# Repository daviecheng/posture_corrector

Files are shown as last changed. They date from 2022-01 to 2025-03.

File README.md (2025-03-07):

# Wearable Posture Corrector Device

## Summary
> A wearable device that alerts the user after prolonged slouching.

Video demonstration is in my GitHub page [here](https://daviecheng.github.io/posture.html)

## Context
- This project utilizes a Scalable, Efficient, and Fast classifieR (SEFR) machine learning algorithm.
  - Fast in both training and prediction while maintaining resource efficiency.
  - Low-power consumption with minimal memory footprint, making it ideal for microcontroller applications.
  - This project uses the `micromlgen` library from this [post](https://eloquentarduino.github.io/2020/07/sefr-a-fast-linear-time-classifier-for-ultra-low-power-devices/).
- The classifier uses 600 training data samples (300 samples each for slouching and non-slouching)
- Input features to the SEFR classifier 
  - Mean acceleration along the X, Y, Z axes
  - Mean RMS acceleration along the X, Y, Z axes
- Device components
  - ATmega328 MCU
  - Lithium Battery Charging Board
  - Pushbutton Power Switch 
  - 3D printed case enclosure
  - Piezo used as an alarm

## Setup
1. Extract training data for both slouching and non-slouching.
2. Copy the training data to a .csv file and label the features as 1 for slouching and 0 for non-slouching.
3. Run the `sefr_ml.py` Python script in `/scripts` with the training data .csv file to generate the C code for the SEFR classifier using the `micromlgen` library.
4. Copy the output and save as a C header file to be included in the project.
5. Use the header file and call the `predict()` function to make predictions using the trained classifier.

## Schematic
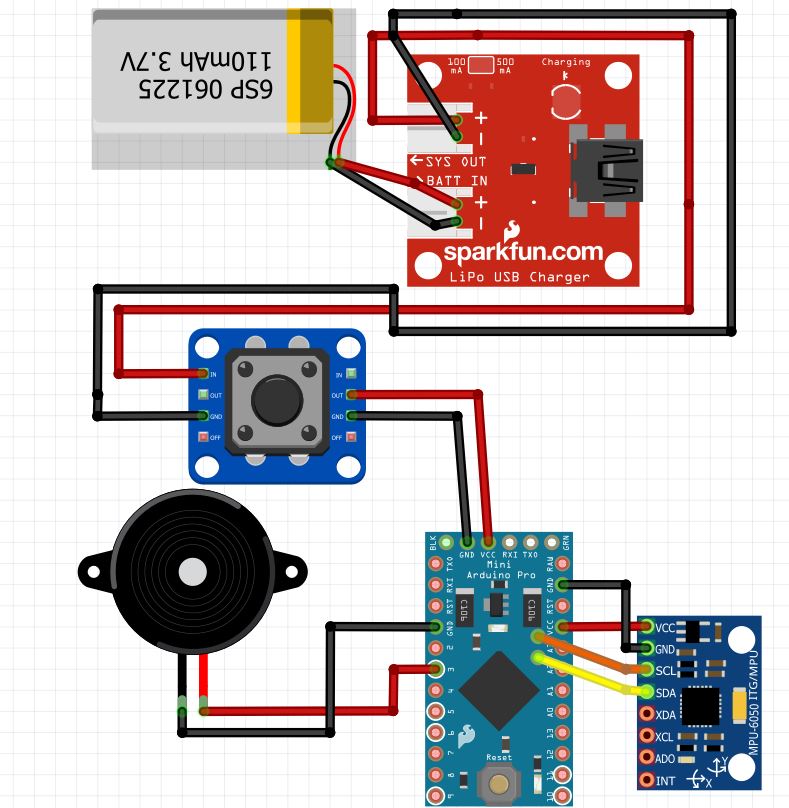
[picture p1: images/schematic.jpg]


## Sequence Diagram
> The device is set to alert the user after approximately 7 seconds of continuous slouching. This setting can be adjusted in the code according to the user's preferences.
```mermaid
sequenceDiagram
    actor User
    participant Power as PowerModule
    participant Manager as PostureManager
    participant SEFR as Classifier
    participant Buzzer as Alarm

    User->>Power : User turns on the device
    Power->>Manager : Setup MPU sensor
    loop Every 2.4 seconds
        User->>Manager : Collects 10 Motion Samples
        Manager->>Manager : Feature extraction
        Manager->>SEFR: Predict
        SEFR->>Manager: Result
        alt Slouching
            Manager->>Manager: Increment Conesecutive Slouches
            alt Consecutive slouches >= 3
                Manager->>Buzzer: Sound Alarm
            end
        else Else
            Manager->>Manager : Reset consecutive slouches
        end

        # Power off flow
        alt Shutdown event
            User->>Power : User turns off the device
        end

    end
```

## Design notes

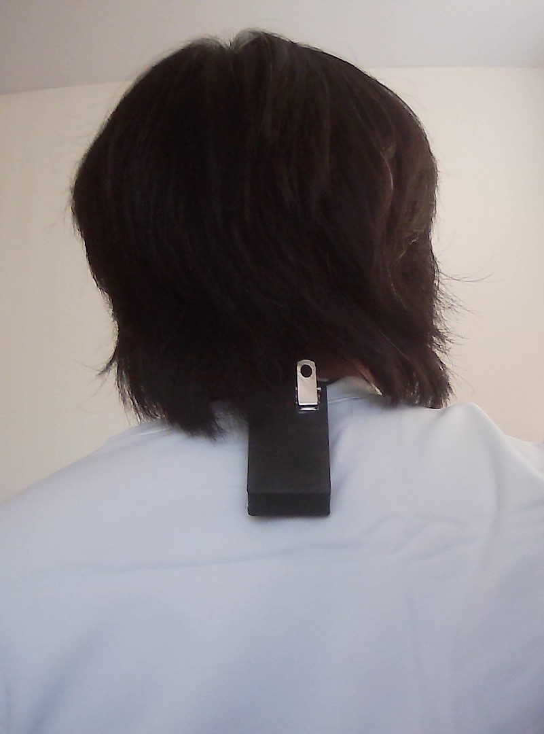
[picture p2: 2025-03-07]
images/device_wear.jpg

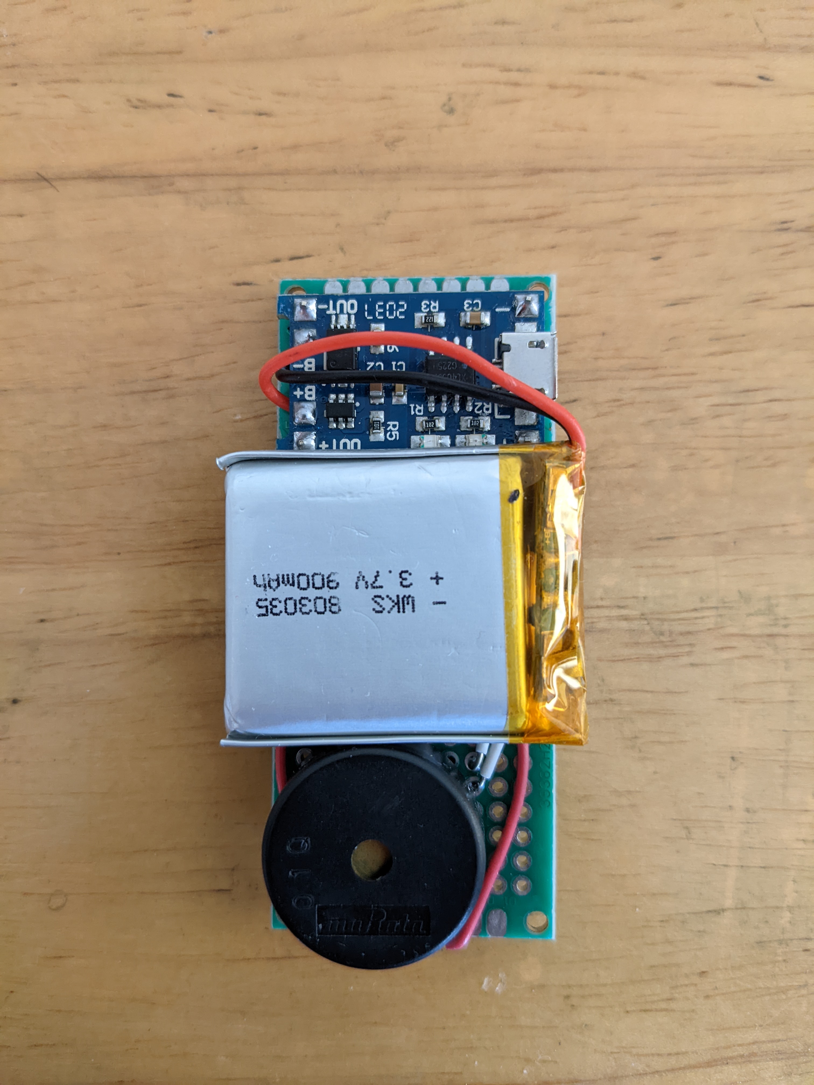
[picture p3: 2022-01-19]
images/device_back.jpg

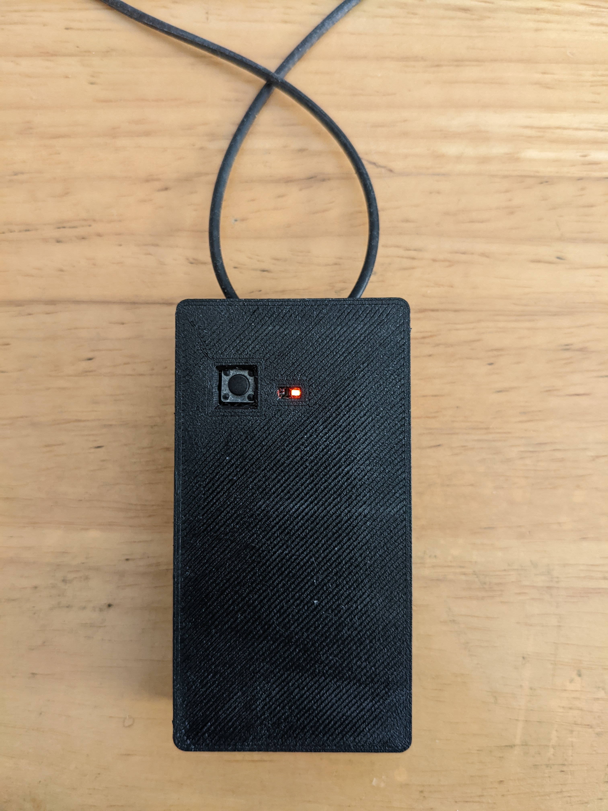
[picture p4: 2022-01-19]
images/device_on.jpg

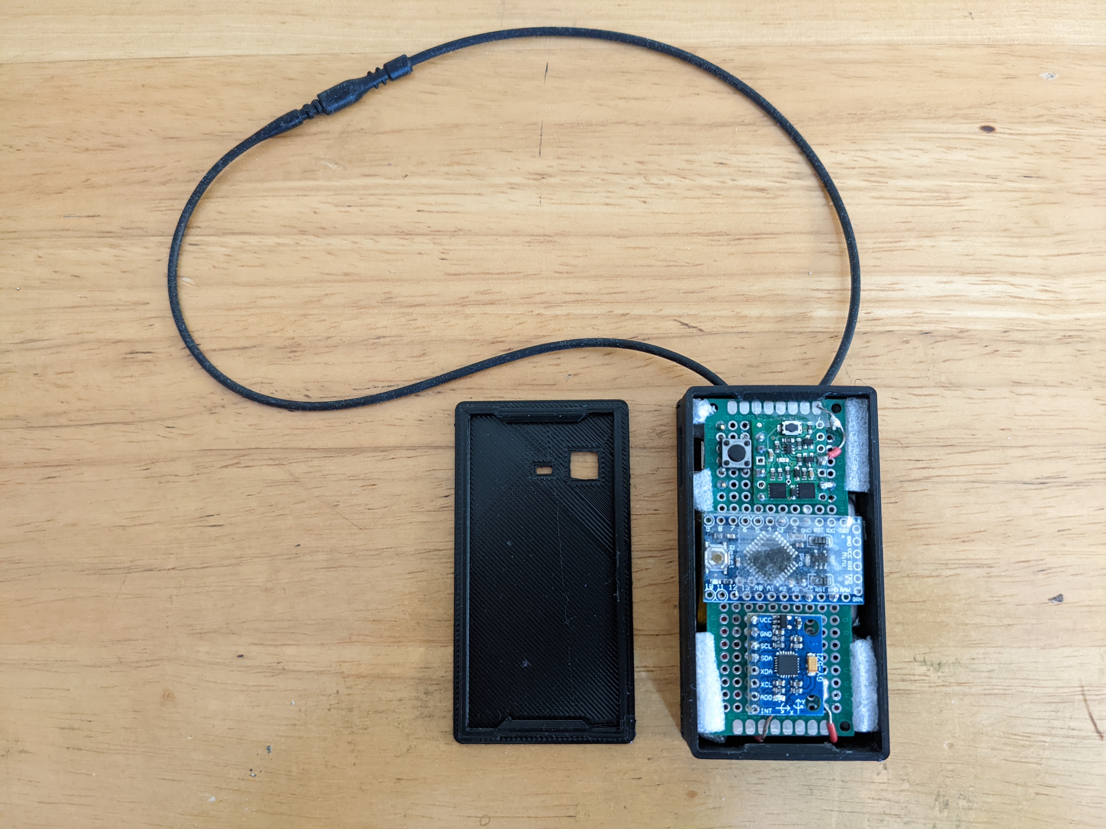
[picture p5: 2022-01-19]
images/device_open_enclosure.jpg

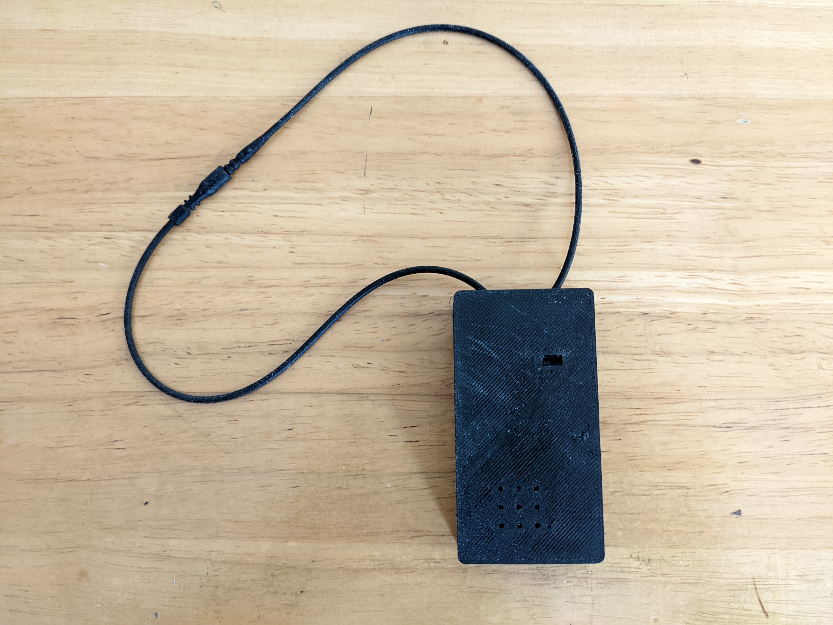
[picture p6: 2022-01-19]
images/device_enclosure_back.jpg

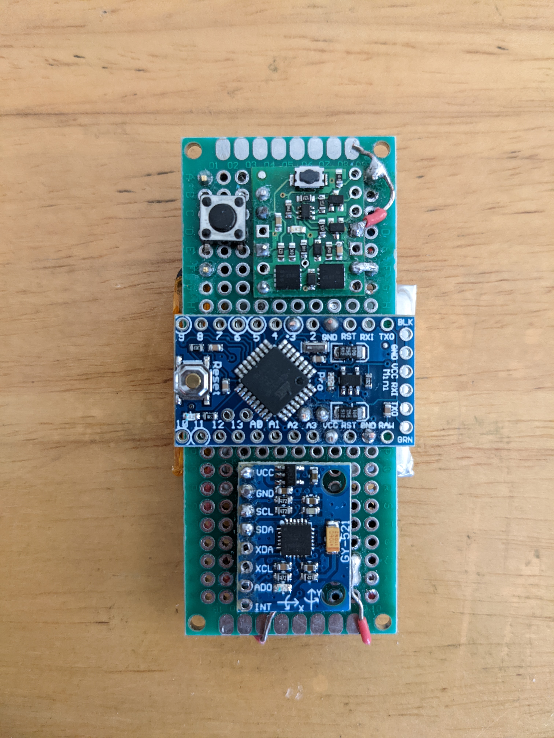
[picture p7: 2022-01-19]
images/device_front.jpg

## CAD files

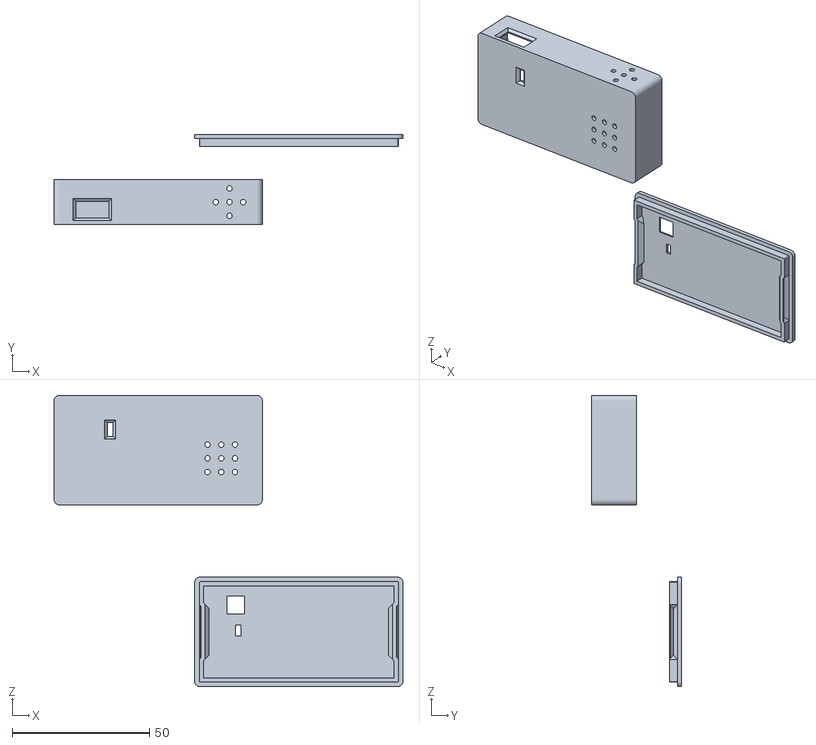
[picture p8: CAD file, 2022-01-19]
docs/Posture Project Box.stl
127.3 x 33.0 x 106.3

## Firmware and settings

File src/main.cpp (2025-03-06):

#include "posture_manager.hpp"

posture::PostureManager posture_manager;

static const int max_number_slouches = 3;
int consecutive_slouches = 0;

void setup()
{
    Serial.begin(115200);
    posture_manager.setup_mpu();
}

void loop()
{
  /*
   * Setting: ATmega328P (3.3V, 8 MHz) 
   * 
   * Test measurement table showing the duration of each prediction interval based on the
   * clock frequency setting. Each prediction interval consists of 10 data samples. As the
   * clock frequency is divided, the prediction interval duration doubles with each setting.
   * 
   * CLKPR  | Time Taken for 1 Prediction Interval
   * -------------------------------------------------
   * 0x00   | 0.15 seconds
   * 0x01   | 0.30 seconds
   * 0x02   | 0.60 seconds
   * 0x03   | 1.20 seconds
   * 0x04   | 2.40 seconds
   * 
   * The CLKPR=0x04 setting was chosen to maximize battery life.
   * A single interval may not accurately reflect slouching due to brief, unexpected movements.
   * Considering at least 3 consecutive prediction intervals to determine slouching.
   * 
   */

    posture_manager.gather_duration_data();
    posture_manager.calculate_duration_features();
    bool is_slouching = posture_manager.predict_slouch_status();

    if (is_slouching)
    {
        consecutive_slouches += 1;
    }
    else
    {
        consecutive_slouches = 0;
    }

    if (consecutive_slouches >= max_number_slouches)
    {
        tone(3, 700, 50);
    }
}

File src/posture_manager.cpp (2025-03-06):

#include "posture_manager.hpp"

#include <Wire.h>

namespace posture
{

PostureManager::PostureManager() {}

void PostureManager::gather_duration_data()
{
    for (int i = 0; i < number_samples_per_duration; i++)
    {
        read_mpu_accelerometer();
        _mpu_accelerometer_duration_data[i][0] = _mpu_accelerometer_data[0];
        _mpu_accelerometer_duration_data[i][1] = _mpu_accelerometer_data[1];
        _mpu_accelerometer_duration_data[i][2] = _mpu_accelerometer_data[2];
        delay(sample_delay_ms);
    }
}

void PostureManager::print_duration_data()
{
    for (int i = 0; i < number_samples_per_duration; i++)
    {
        for (int j = 0; j < 3; j++)
        {
            Serial.print(_mpu_accelerometer_duration_data[i][j]);
            Serial.print(" ");
        }
        Serial.println();
    }
}

void PostureManager::calculate_duration_features()
{
    float acceleration_sum[3]          = {0, 0, 0};
    float acceleration_squared_sum[3]  = {0, 0, 0};

    for (int i = 0; i < number_samples_per_duration; i++)
    {
        // Acceleration sum x, y, z
        acceleration_sum[0] += _mpu_accelerometer_duration_data[i][0];
        acceleration_sum[1] += _mpu_accelerometer_duration_data[i][1];
        acceleration_sum[2] += _mpu_accelerometer_duration_data[i][2];

        // RMS acceleration x, y, z
        acceleration_squared_sum[0] += pow(_mpu_accelerometer_duration_data[i][0], 2);
        acceleration_squared_sum[1] += pow(_mpu_accelerometer_duration_data[i][1], 2);
        acceleration_squared_sum[2] += pow(_mpu_accelerometer_duration_data[i][2], 2);
    }

    for (int i = 0; i < 3; i++)
    {
        // Mean acceleration x, y, z
        _classifier_inputs[i] = acceleration_sum[i] / number_samples_per_duration;

        // RMS acceleration
        _classifier_inputs[i + 3] = sqrt(acceleration_squared_sum[i] / number_samples_per_duration);
    }
}

void PostureManager::print_duration_features()
{
    for (int i = 0; i < 6; i++)
    {
        Serial.print(_classifier_inputs[i]);
        Serial.print("\t");
    }
    Serial.println();
}

void PostureManager::setup_mpu()
{
    Wire.begin();
    Wire.beginTransmission(0x68); //This is the I2C address of the MPU (b1101000/b1101001 for AC0 low/high datasheet sec. 9.2)
    Wire.write(0x6B);             //Accessing the register 6B - Power Management (Sec. 4.28)
    Wire.write(0b00000000);       //Setting SLEEP register to 0. (Required; see Note on p. 9)
    Wire.endTransmission();  
    Wire.beginTransmission(0x68); //I2C address of the MPU
    Wire.write(0x1B);             //Accessing the register 1B - Gyroscope Configuration (Sec. 4.4) 
    Wire.write(0x00000000);       //Setting the gyro to full scale +/- 250deg./s 
    Wire.endTransmission(); 
    Wire.beginTransmission(0x68); //I2C address of the MPU
    Wire.write(0x1C);             //Accessing the register 1C - Acccelerometer Configuration (Sec. 4.5) 
    Wire.write(0b00000000);       //Setting the accel to +/- 2g
    Wire.endTransmission();

    Serial.println("MPU Setup Complete");
}

void PostureManager::read_mpu_accelerometer()
{
    Wire.beginTransmission(0x68);        //I2C address of the MPU
    Wire.write(0x3B);                    //Starting register for Accel Readings
    Wire.endTransmission();
    Wire.requestFrom(0x68,6);            //Request Accel Registers (3B - 40)
    while(Wire.available() < 6);
    long x_acceleration = Wire.read()<<8|Wire.read(); //Store first two bytes into x_acceleration
    long y_acceleration = Wire.read()<<8|Wire.read(); //Store middle two bytes into y_acceleration
    long z_acceleration = Wire.read()<<8|Wire.read(); //Store last two bytes into z_acceleration
  
    // acceleration values in [g]
    _mpu_accelerometer_data[0] = x_acceleration / 16384.0; 
    _mpu_accelerometer_data[1] = y_acceleration / 16384.0; 
    _mpu_accelerometer_data[2] = z_acceleration / 16384.0;
}

bool PostureManager::predict_slouch_status()
{
    return _classifier.predict(_classifier_inputs);
}

} // namespace posture

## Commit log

2025-03-03 Update project to use PlatformIO
    [Posture Project Box.stl, posture_td.csv]
2025-03-04 Add sequence diagram for device workflow
2025-03-07 Move image and media files to own folder
    [Posture Project Box.stl]
